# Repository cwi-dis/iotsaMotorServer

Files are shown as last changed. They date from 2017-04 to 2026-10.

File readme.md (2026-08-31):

# iotsaMotorServer - web server to drive a stepper motor




This is a wifi http server to control a steppermotor, which can then be used to move something, under control of a REST interface. It is built using the iotsa framework for ESP8266.

Home page is <https://github.com/cwi-dis/iotsaMotorServer>.
This software is licensed under the [MIT license](LICENSE.txt) by the   CWI DIS group, <http://www.dis.cwi.nl>.

One application that has been built with this server is a device that moves a plant (or anything else) up and down, so you can use the height of the plant to visualise the value of a variable. An example of such a variable would be your current electricity consumption, the temperature (inside or outside), the number of minutes until it starts to rain again, or any other scalar value you can find on the internet.

At the moment minimum and maximum position and conversion rate of values to steps are hard-coded, so you need to modify the code to change these.

## Software requirements

* PlatformIO (primary) or the Arduino IDE.
* The [iotsa framework](https://github.com/cwi-dis/iotsa) — pulled in automatically by `platformio.ini`.
* The AccelStepper library by Mike McCauley — in the PlatformIO / Arduino library registries as `AccelStepper` (`platformio.ini` lists it in `lib_deps`).

## Hardware requirements

* a iotsa board. Alternatively another esp8266 board, such as an ESP-12 or ESP-201 can also be used.
* A stepper motor (5-12v) such as the 28BYJ-48 (5 volt 4-input halfstep motor).
* An ULN2003A (darlington driver array).
* A microswitch to detect the minimum position, and optionally a second one to detect maximum position.
* Mechanical hardware to put everything together.

## Electronics

In _extras/fritzing_ you find a Fritzing schematic to allow you to build the server plus the steppermotor driver. As-is the code is meant to interface to a 5-wire steppermotor such as the cheap and popular 28BYJ-48 (5 volt 4-input halfstep motor), but similar motors should work as well. For other motors (fullstep, different wiring) you will need to modify the code.

You don't need Fritzing to build the board, if you have a iotsa board there is a schematic in [extras/fritzing/IotsaMotorServerBoard.pdf](extras/fritzing/IotsaMotorServerBoard.pdf) to show you how to populate the board. The iotsa board can handle 12 volt, so you can use a 12v stepper motor if that is more convenient.

## Mechanics

If you want to build an assembly to pull a plant up and down (or anything else up to a weight of about 500 grams) you can find a 3D-printable design at <http://www.thingiverse.com/thing:2281030>. 

The Thingyverse page has links to the Tinkercad files, you will probably need to tweak the design a little to fit your application.

The page also has assembly intructions.

## Building the software

Near the top of `mainMotorServer.cpp` you need to define `numMotors` and parameters such as `STEPS_PER_MM`. Most of these will have to be determined by trial and error. You need at least one microswitch per motor, to find the minimum (zero) position on boot.

Next you specify GPIO pins for the stepper motor(s) and the zero-detect microswitch(es).

Now compile, and flash either over USB/serial or (if your esp board supports it) over-the-air.

## Operation

The first time the board boots it creates a Wifi network with a name similar to _config-iotsa1234_.  Connect a device to that network and visit <http://192.168.4.1>. Configure your device name (let's say _motor_, as an example), WiFi name and password, and after reboot the iotsa board should connect to your network and be visible as <http://motor.local>.

There is nothing more to configure in the web interface, all settings are made in the code. This is on purpose: settings like GPIO pins used and number of steps needed to raise the object 1mm depend on the hardware and not changeable on the fly.

When the board is powered on (or reset) it will start pulling in the wire until the microswitch engages, to determine the zero position, and then move back a few millimeter. You will probably need to fiddle the microswitch and the end stop hardware to get this to work consistently.

The server provides a REST-like interface on <http://motor.local/stepper> and <http://motor.local/stepper/0> for reading the current state. Changing positions, however, is done with an _http GET_ request to <http://motor.local/stepper/0?pos=123>, which will set _target_ to _123_ millimeter and start moving there.

If you move to a large negative value the zero-limit microswitch will engage, the motor will stop and the position will be set to zero. This can be used to recalibrate (without rebooting), if needed.

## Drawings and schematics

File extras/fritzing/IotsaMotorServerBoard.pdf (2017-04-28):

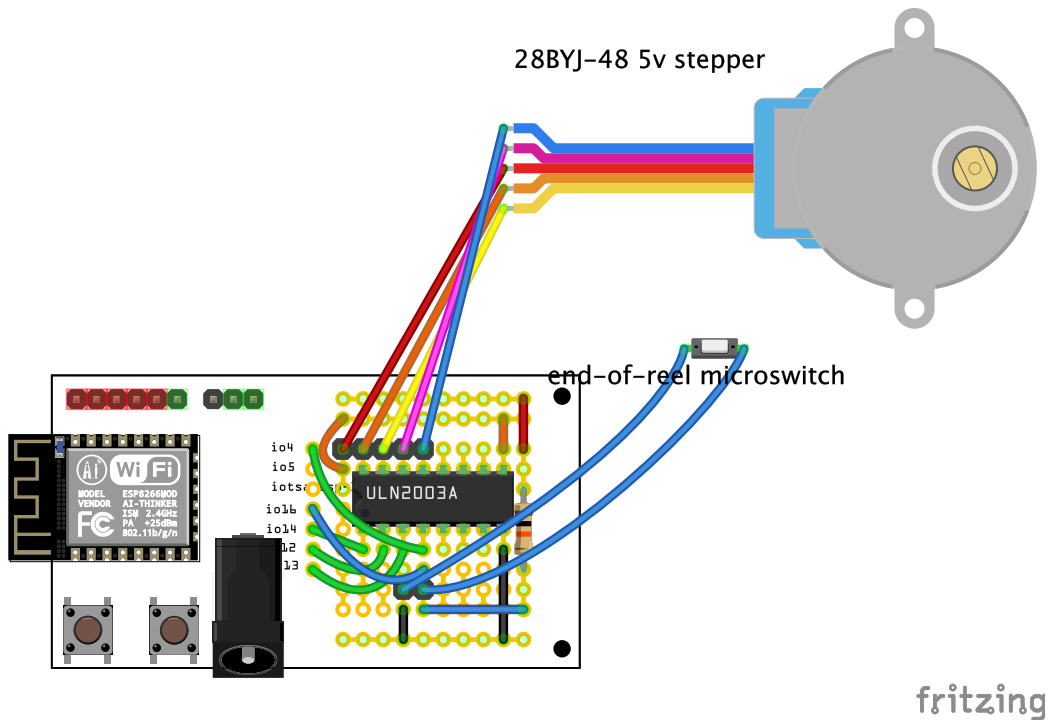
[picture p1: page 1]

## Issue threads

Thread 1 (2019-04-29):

Control two steppers

BeckElectronics, 2019-04-29:
Hello
First thank you for this great project, and share it.
I think it's possible to add a second stepper, but I'm a little lost.
-> What can I do in the code to control two steppers ?
Thank you so much. ;-)

jackjansen, 2019-04-30:
You need to set `numMotors` to 2 (line 48) and then add the pin information for the second motor to `stepperMot` and `zeroDetectPin`, and an extra 0 to `motorLimit`.

*But*, and this is a large but: assuming you're using an ESP8266 you don't have enough hardware pins to drive two motors. You need 5 pins per motor (but you could conceivably do away with the zero-detect pin, then you need 4) and there are only 6 easily usable digital IO pins on the esp8266.

If you're using an ESP32 you should have more than enough GPIO pins, but then be warned that I've never used iotsaMotorServer on an ESP32 so there may be surprises...

BeckElectronics, 2019-05-01:
Thank you for reply.
I've forgot to say I use the ESP12E with Lollin kit, it offer normaly 10 GPIO :
[https://cdn.instructables.com/FPV/E4YC/IKLFP40J/FPVE4YCIKLFP40J.LARGE.jpg](url)

It's ok for `numMotors`  but, to set informations in `stepperMot` and `zeroDetectPin` I don't see how to do.
I've seen this exemple in data on AccelStepper library of Airspayce website :
[https://www.airspayce.com/mikem/arduino/AccelStepper/MultipleSteppers_8pde-example.html](url)
or this to use MultiStepper class :
[https://www.airspayce.com/mikem/arduino/AccelStepper/MultiStepper_8pde-example.html](url)

My main problem is that in this exemples they use
`AccelStepper stepper2(AccelStepper::FULL4WIRE, 6, 7, 8, 9);`
(in 1st airspayce link )
instead of
`AccelStepper stepperMot[numMotors]= {
  AccelStepper(AccelStepper::HALF4WIRE, motor1Pin1, motor1Pin3, motor1Pin2, motor1Pin4, true)
};`
in IotsaMotorServer code.
That's why maybe I don't undestand how to do.

Maybe I must to precise I want to control two steppers independantly ;-)
Thanks.

jackjansen, 2019-05-02:
First of all: be careful with assuming 10 GPIO pins. Pins 0 and 2 have a special rule during power up and reset. After that you can use them as outputs, so you may be okay with that. 1 and 3 have another issue: they are normally used for the UART. And if you want to use _iotsa_ it will initialise the UART early during startup, so you will have to disable that.

Second, as to `zeroDetectPin`: it should be fairly easy to remove all references to it if you don't want to do zero detection. (In the code here it is connected to a microswitch that engages whenever the cable that the motor pulls up has reached its maximum, to forestall the motor trying to continue rolling up if the cable is at the end).

Third, as to the `stepperMot` initialisation: the arguments call to the `AccelStepper()` constructor depend on the actual motor you have and the driver IC you use. Check the library documentation (it is included in the _.h_ file, for example at <https://github.com/waspinator/AccelStepper/blob/master/src/AccelStepper.h>. And let me warn you that you're probably going to get things wrong at 5 times (with at best the motor only doing _brp. brp. brp._ in stead of moving the way you want it). At least, I did:-)

Actually, for experimentation I would suggest that you start with only _one_ stepper motor, using the existing code with `zeroDetectPin` removed. Then only when you get that working you worry about the second motor...

BeckElectronics, 2019-05-04:
Okay I've successfully finis, it work good.
I've tried some pins, somes stay HIGH in first boot, but since first move they work normaly.

Thank you very much for the help,  and for taking the time to guide me :)

Closed 2019-05-04.

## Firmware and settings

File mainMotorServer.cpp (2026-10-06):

//
// RESTful stepper-motor server. Controls how much cable a stepper motor has
// unrolled -- e.g. to hang a plant at a dynamically determined height, so its
// position visualises some scalar value (power use, temperature, minutes until
// rain, ...).
//
// Built on the iotsa framework. All tuning -- numMotors, STEPS_PER_MM, the GPIO
// pins for the motor(s) and the zero-detect microswitch(es) -- is compile-time;
// see the constants below and readme.md.
//

#include "iotsa.h"
#include <AccelStepper.h>

IotsaApplication application("Iotsa Stepper Motor Server");

// Declaration of the Stepper Motor module
class IotsaStepperMod : public IotsaBaseModule {
public:
  IotsaStepperMod(IotsaApplication &_app) : IotsaBaseModule(_app) {}
  void setup() override;
  void lateSetup() override;
  void loop() override;
  String info() override;
private:
  void handleMotorIndex();
  String handleMotorStatus(int num);
  void handleMotor(int num);
};

//
// Steppermotor declarations
//
#define numMotors 1
#define STEPS_PER_MM  (-104) // This depends on spool size, motor factors and more.
#define MOTOR_MAX_SPEED 700 // In steps per second, positive
#define MOTOR_ACCEL 100
#define MOTOR_KEEP_POWER  // Define to keep power on motors when not moving (may help against slipping)
#define STEPPER_TIMEOUT 300000 // 5 minutes max for positioning motor

// Pinout for first motor. Note (below) that the 28BYJ-48 needs pins to be stepped 1-3-2-4.
#define motor1Pin1 4  // GPIO 4 -> ULN2003 IN1 -> 28BYJ-48 blue
#define motor1Pin2 13  // GPIO 13 -> ULN2003 IN2 -> 28BYJ-48 pink
#define motor1Pin3 12  // GPIO 12 -> ULN2003 IN3 -> 28BYJ-48 yellow
#define motor1Pin4 14  // GPIO 14 -> ULN2003 IN4 -> 28BYJ-48 orange
#define motor1ZeroPin 16 // GPIO 16 connected to zeroing input

AccelStepper stepperMot[numMotors]= {
  AccelStepper(AccelStepper::HALF4WIRE, motor1Pin1, motor1Pin3, motor1Pin2, motor1Pin4, true)
};

int zeroDetectPin[numMotors] = {
  motor1ZeroPin
};

long motorLimit[numMotors] = {
  0
};

void
IotsaStepperMod::handleMotorIndex() {
  String message = "{\"numMotors\":";
  message += String(numMotors);
  message += ", \"uptime\":";
  message += String(millis());
  message += "}";
  app.server->send(200, "application/json", message);
}

void IotsaStepperMod::setup() {
  for (int i=0;i<=numMotors-1;i++) {
    stepperMot[i].setMaxSpeed(MOTOR_MAX_SPEED);
    stepperMot[i].setAcceleration(MOTOR_ACCEL);

    if (zeroDetectPin[i]) {
      // This motor has a zero-detection pin. Move motor in negative direction until we
      // detect zero (pin goes to GND), then slowly zero in.
      IotsaSerial.println("pinMode");
      pinMode(zeroDetectPin[i], INPUT_PULLUP);
      IotsaSerial.println("To minus 5 meter");
      stepperMot[i].setSpeed(0);
      stepperMot[i].setCurrentPosition(0);
      stepperMot[i].moveTo(-5000 * STEPS_PER_MM);
      unsigned long startTime = millis();
      IotsaSerial.println("Moving back");
      while(digitalRead(zeroDetectPin[i]) != LOW && millis() < startTime + STEPPER_TIMEOUT) {
        stepperMot[i].run();
        delay(1);
      }
      IotsaSerial.println("To 1 cm");
      stepperMot[i].setSpeed(0);
      stepperMot[i].setCurrentPosition(0);
      stepperMot[i].moveTo(10 * STEPS_PER_MM);
      IotsaSerial.println("Moving forward");
      while(stepperMot[i].distanceToGo() != 0) {
        stepperMot[i].run();
        delay(1);
      }
      IotsaSerial.println("done");
      if (millis() >= startTime + STEPPER_TIMEOUT) {
        IFDEBUG IotsaSerial.println("Motor timeout");
      }
      if (digitalRead(zeroDetectPin[i]) == LOW) {
        IFDEBUG IotsaSerial.println("Zero-switch still engaged");
      }
      stepperMot[i].setSpeed(0);
      stepperMot[i].setCurrentPosition(0);
    } else {
      // No zero-detection input. Go to position zero, whatever that was (probably just where we are now)
      stepperMot[i].setSpeed(0);
      stepperMot[i].moveTo(0);
    }
#ifndef MOTOR_KEEP_POWER
    // Disable outputs
    stepperMot[i].disableOutputs();
#endif
  IFDEBUG IotsaSerial.println("Stepper initialized");
  }
}

String
IotsaStepperMod::handleMotorStatus(int num) {
  String message = "{\"id\":\"";
  message += String(num);
  message += "\", \"pos\":";
  message += String(stepperMot[num].currentPosition() / STEPS_PER_MM);
  message += ", \"target\":";
  message += String(stepperMot[num].targetPosition() / STEPS_PER_MM);
  message += ", \"speed\":";
  message += String(stepperMot[num].speed() / STEPS_PER_MM);
  if (motorLimit[num]) {
    message += ", \"limit\":";
    message += String(motorLimit[num]);
  }
  if (zeroDetectPin[num]) {
    message += ", \"inrange\":";
    message += String(digitalRead(zeroDetectPin[num]));
  }
  message += "}";
  return message;
}

void
IotsaStepperMod::handleMotor(int num) {
  long pos = 0;
  for (uint8_t i=0; i<app.server->args(); i++){
    if( app.server->argName(i) == "pos") {
      pos = atol(app.server->arg(i).c_str());
      if (pos < 0) pos = 0;
      if (motorLimit[num] && pos > motorLimit[num]) pos = motorLimit[num];
      stepperMot[num].moveTo(pos*STEPS_PER_MM);
#ifndef MOTOR_KEEP_POWER
      stepperMot[num].enableOutputs();
#endif
    }
  }
  app.server->send(200, "application/json", handleMotorStatus(num));
}

unsigned long ignoreZeroDetectUntil = 0;

void IotsaStepperMod::loop() {
  if (millis() > ignoreZeroDetectUntil) ignoreZeroDetectUntil = 0;
  for(int i=0; i<numMotors; i++) {
    bool shouldRun = (stepperMot[i].distanceToGo() != 0);
    stepperMot[i].run();
    if (shouldRun ) {
#ifndef MOTOR_KEEP_POWER
      if (stepperMot[i].distanceToGo() == 0) {
        // Disable outputs if we have reached the target
        stepperMot[i].disableOutputs();
      } else
#endif
      if (zeroDetectPin[i] && digitalRead(zeroDetectPin[i]) == LOW && ignoreZeroDetectUntil > 0) {
        // We were moving backward. Back off and re-zero, move out 5 cm.
        IFDEBUG IotsaSerial.println("Zero-detect switch hit. Re-init motor.");
        setup();
      }
    }
  }
}

void IotsaStepperMod::lateSetup() {
  app.server->on("/stepper", std::bind(&IotsaStepperMod::handleMotorIndex, this));
  for (int i=0; i < numMotors; i++) {
    String loc = "/stepper/" + String(i);
    app.server->on(loc.c_str(), std::bind(&IotsaStepperMod::handleMotor, this, i));
  }
}

String IotsaStepperMod::info() {
  // Return some information about this module, for the main page of the web server.
  String rv = "<p>See <a href='/stepper'>/stepper</a> for info";
  for (int i=0; i < numMotors; i++) {
    rv += ", <a href='/stepper/" + String(i) + "'>/stepper/" + String(i) + "</a> for motor " + String(i);
  }
  rv += ".</p>";
  return rv;
}

// Instantiate the module, and install it in the framework
IotsaStepperMod stepperMod(application);

// Standard setup() method, hands off most work to the application framework
void setup(void){
  application.setup();
  application.lateSetup();
#ifndef ESP32
  ESP.wdtEnable(WDTO_120MS);
#endif
}

// Standard loop() routine, hands off most work to the application framework
void loop(void){
  application.loop();
}

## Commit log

2017-04-28 Renaming things to prepare for git migration
    [IotsaMotorServerBoard.fzz]
2019-05-05 Add optional LED module
2020-04-16 Don't include esp32_https_server_compat
2021-01-03 Build all iotsa products for at least nodemcuv2 and esp32thing
2021-01-03 Use board_build.ldscript
2021-01-03 Fixed esp32 problem
2025-04-27 Updated arduino build job
2026-07-28 Disable HTTPS on the esp8266 env - BearSSL too slow/unstable in practice
    Config PUTs over HTTPS took up to a minute and intermittently crashed
    the device inside Espressif's WiFi SDK (SoftAP probe-response
    handling). Same class of resource exhaustion as cwi-dis/iotsa#159.
    esp32thing is unaffected and keeps HTTPS via the common build flags.
2026-08-12 Use cmArduinoJWT fork instead of unmaintained ArduinoJWT
    Fixes cwi-dis/iotsa#184
2026-08-13 Replace fork --git-url installs with Library Manager references in Arduino CI
    cmArduinoJWT and esp32_idf5_https_server_compat are now published in the
    Arduino Library Manager, so the arduino-cli workflow no longer needs
    --git-url installs for them (esp32_idf5_https_server resolves
    transitively via esp32_idf5_https_server_compat's own depends=). iotsa
    itself is still installed via --git-url, pinned to the branch/ref under
    test.
    cwi-dis/iotsa#96
2026-08-13 arduino-cli: force a fresh library index before name-based lib installs
    The previous commit switched cmArduinoJWT and esp32_idf5_https_server_compat
    from --git-url installs to name-based Library Manager lookups. That exposed
    a latent bug in the "Cache Arduino CLI" step: its cache key hashes
    *_index.json in the repo working directory, which doesn't exist here, so
    the key is effectively static and a cache-hit silently restores whatever
    library_index.json was saved on the very first run -- forever, since
    arduino-cli only auto-downloads that index when it's completely absent,
    never when it's merely stale.
    Confirmed locally (with arduino-cli installed via brew): installing
    cmArduinoJWT against a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
2026-08-14 ci: bump GitHub Actions to current majors (checkout@v7, setup-python@v7, upload-artifact@v7, cache@v6)
    These were pinned to versions from 2020-2021 (checkout@v2, setup-python@v2 -
    both Node16, upload-artifact@v4, cache@v2), well past their supported
    window. Matches the versions already verified working in iotsa itself.
2026-08-31 Migrate to iotsa v3 API + #149 pass
    v3 (IotsaStepperMod is a non-API module -- hand-registered JSON routes, no
    config, no getHandler/putHandler):
    - IotsaMod -> IotsaBaseModule (not IotsaModule), matching iotsaSmartMeter's
    IotsaP1Mod;
    - serverSetup() -> lateSetup(); server-> -> app.server-> in lateSetup() and
    the /stepper + /stepper/N handler bodies;
    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
2026-10-05 Re-vendor iotsa board definitions; drop redundant min_spiffs.csv lines
    Refreshes iotsa-board-traits.ini / iotsa-board-defs.ini from iotsa
    develop (last vendored 2026-08-31). Picks up:
    - espressif32 platform pinned to 7.1.3 (cwi-dis/iotsa#269)
    - board_build.filesystem = littlefs, so `pio run -t uploadfs` builds an
    image the firmware can mount (cwi-dis/iotsa#269)
    - min_spiffs.csv as the default partition layout for all 4MB ESP32
    boards (cwi-dis/iotsa#245), making local board_build.partitions =
    min_spiffs.csv lines redundant -- removed where present
    - the NimBLE host-task stack flag for all ESP32 builds (cwi-dis/iotsa#127)
    Resolved config checked before/after with `pio project config`: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
2026-10-06 Adapt to iotsa's standard modules and per-application authenticator
    Re-vendor iotsa-board-traits.ini / iotsa-board-defs.ini from iotsa
    develop (status LED defines: IOTSA_PIN_LED, IOTSA_LED_NEOPIXEL,
    IOTSA_LED_ACTIVE_LOW).
    - Drop the IotsaWifiMod/IotsaOtaMod declarations: iotsa now creates the
    WiFi and OTA modules automatically (cwi-dis/iotsa#85).
    - Drop the status-LED declaration (NeoPixel on GPIO15): iotsa creates it
    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
